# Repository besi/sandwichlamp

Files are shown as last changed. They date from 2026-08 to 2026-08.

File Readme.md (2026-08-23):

# Sandwich Lamp

## Pinout

| Pin | Function |
|-----|---|
| 13  | Enable 12V |
| 18  | Neopixel |
| 14  | Touch 1 |
| 32  | Touch 2 |
| 4 | Touch 3 |
| 34  | Button 1 |
| 33  | Button 2 |
| 39  | Button 3 |
| 36  | Button 4 |
| 35  | Button X |
| 27  | Radar TX |
| 12  | Radar RX |
| 19  | I2C SCL |
| 23  | I2C SDA |
| 16  | Battery Sens |
| 2 | Brightness |
| 5 | Onboard LED  |
| 0 | OneWire |

## Installation

```
import mip
mip.install("github:robert-hh/BME280")
```

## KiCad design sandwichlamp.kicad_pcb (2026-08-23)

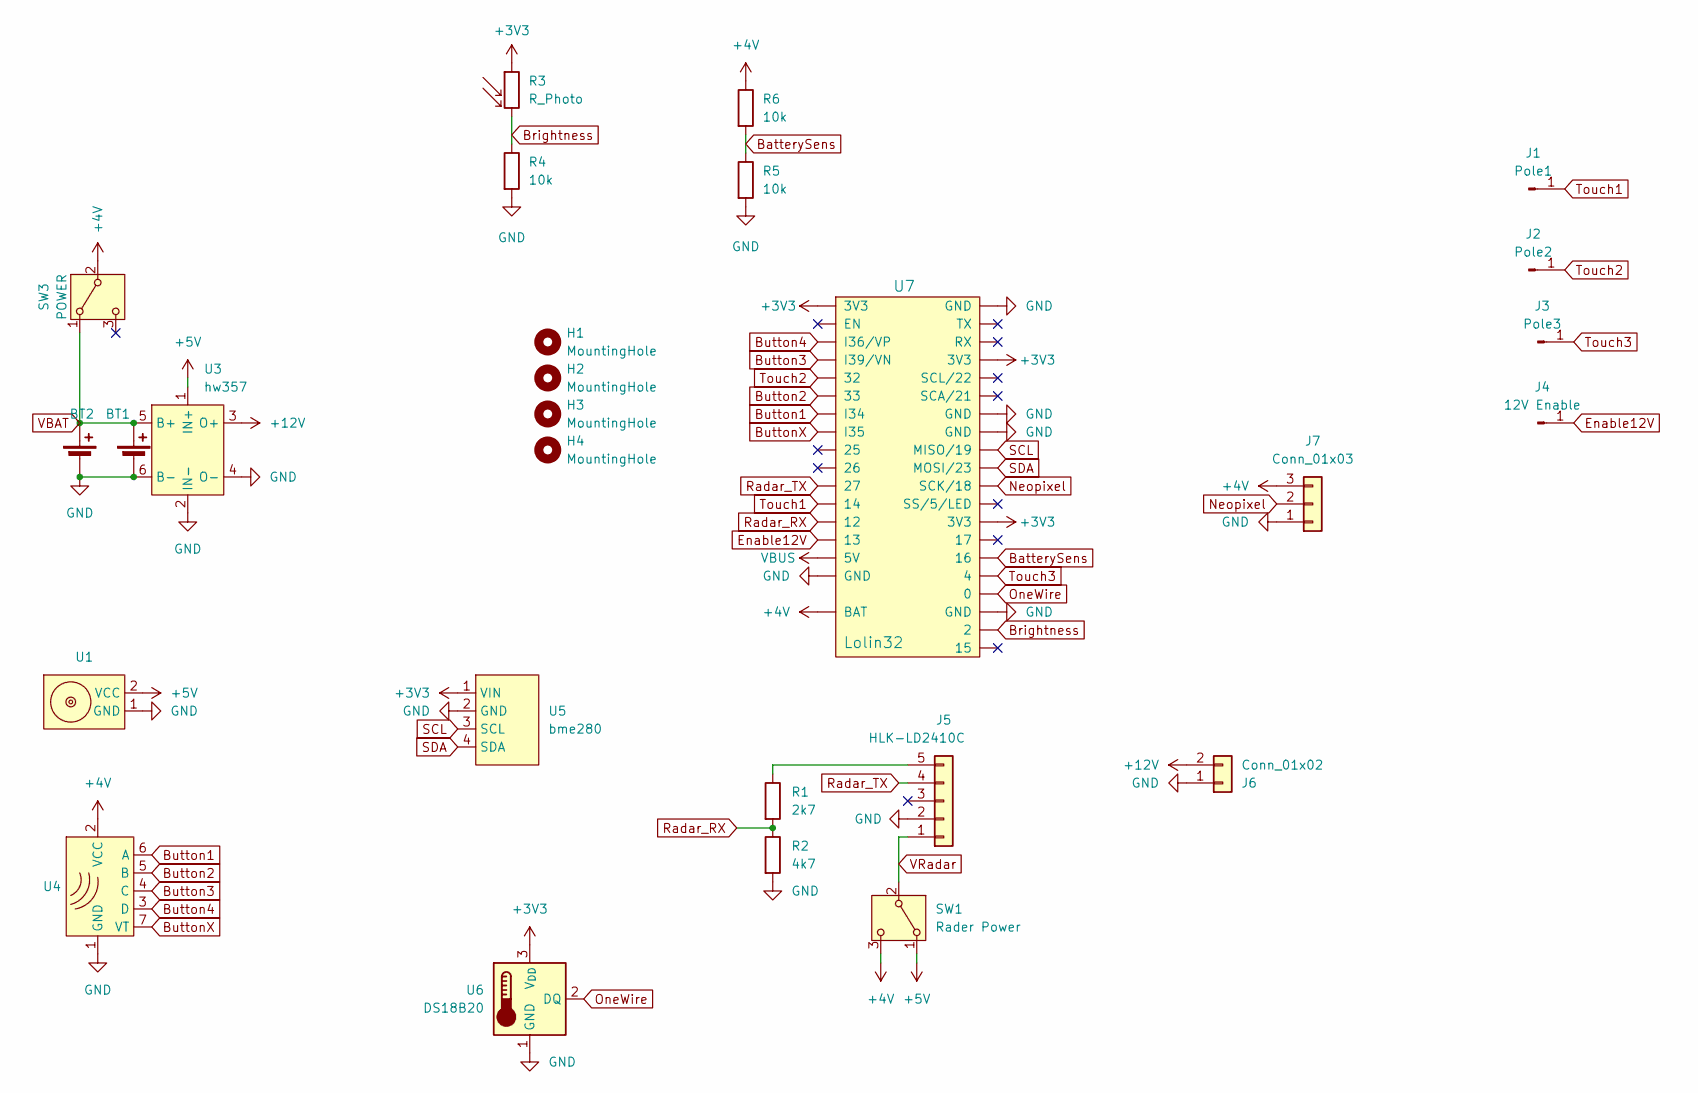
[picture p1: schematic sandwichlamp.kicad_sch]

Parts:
BT1: Battery_Cell; JST_PH_S2B-PH-SM4-TB_1x02-1MP_P2.00mm_Horizontal
BT2: Battery_Cell; JST_PH_B2B-PH-K_1x02_P2.00mm_Vertical
H1, H2, H3, H4: MountingHole; MountingHole_3.2mm_M3
J1: Pole1; MountingHole_4.3mm_M4_ISO7380_Pad_TopOnly
J2: Pole2; MountingHole_4.3mm_M4_ISO7380_Pad_TopOnly
J3: Pole3; MountingHole_4.3mm_M4_ISO7380_Pad_TopOnly
J4: 12V Enable; PinHeader_1x01_P2.54mm_Vertical
J5: HLK-LD2410C; PinHeader_1x05_P2.54mm_Vertical
J6: Conn_01x02; PinHeader_1x02_P2.54mm_Vertical
J7: Conn_01x03; PinHeader_1x03_P2.54mm_Vertical
R1: 2k7; R_Axial_DIN0207_L6.3mm_D2.5mm_P7.62mm_Horizontal
R2: 4k7; R_Axial_DIN0207_L6.3mm_D2.5mm_P7.62mm_Horizontal
R3: R_Photo; R_LDR_5.0x4.1mm_P3mm_Vertical
R4, R5, R6: 10k; R_0805_2012Metric_Pad1.20x1.40mm_HandSolder
SW1: Rader Power; PinHeader_1x03_P2.54mm_Vertical
SW3: POWER; as12ap
U1: magnetic-charger
U3: hw357
U4: RX480E; radio-receiver
U5: bme280
U6: DS18B20; TO-92L_Inline_Wide
U7: Lolin32; lolin32

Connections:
+3V3: R3.1, U5.1 (VIN), U6.3 (V_{DD}), U7.1 (3V3), U7.20 (3V3), U7.29 (3V3)
+4V: J7.3, R6.1, SW1.3 (C), SW3.2 (B), U4.2 (VCC), U7.37 (BAT)
+5V: SW1.1 (A), U1.2 (VCC), U3.1 (IN+)
+12V: J6.2, U3.3 (O+)
BatterySens: R5.1, R6.2, U7.31 (16)
Brightness: R3.2, R4.1, U7.35 (2)
Button1: U4.6 (A), U7.7 (I34)
Button2: U4.5 (B), U7.6 (33)
Button3: U4.4 (C), U7.4 (I39/VN)
Button4: U4.3 (D), U7.3 (I36/VP)
ButtonX: U4.7 (VT), U7.8 (I35)
Enable12V: J4.1, U7.14 (13)
GND: BT1.1 (-), BT2.2 (-), J5.2, J6.1, J7.1, R2.2, R4.2, R5.2, U1.1 (GND), U3.2 (IN-), U3.4 (O-), U3.6 (B-), U4.1 (GND), U5.2 (GND), U6.1 (GND), U7.16 (GND), U7.17 (GND), U7.23 (GND), U7.24 (GND), U7.34 (GND)
Neopixel: J7.2, U7.27 (SCK/18)
unnamed: J5.5, R1.1
OneWire: U6.2 (DQ), U7.33 (0)
Radar_RX: R1.2, R2.1, U7.13 (12)
Radar_TX: J5.4, U7.11 (27)
SCL: U5.3 (SCL), U7.25 (MISO/19)
SDA: U5.4 (SDA), U7.26 (MOSI/23)
Touch1: J1.1, U7.12 (14)
Touch2: J2.1, U7.5 (32)
Touch3: J3.1, U7.32 (4)
VBAT: BT1.2 (+), BT2.1 (+), SW3.1 (A), U3.5 (B+)
VBUS: U7.15 (5V)
VRadar: J5.1, SW1.2 (B)

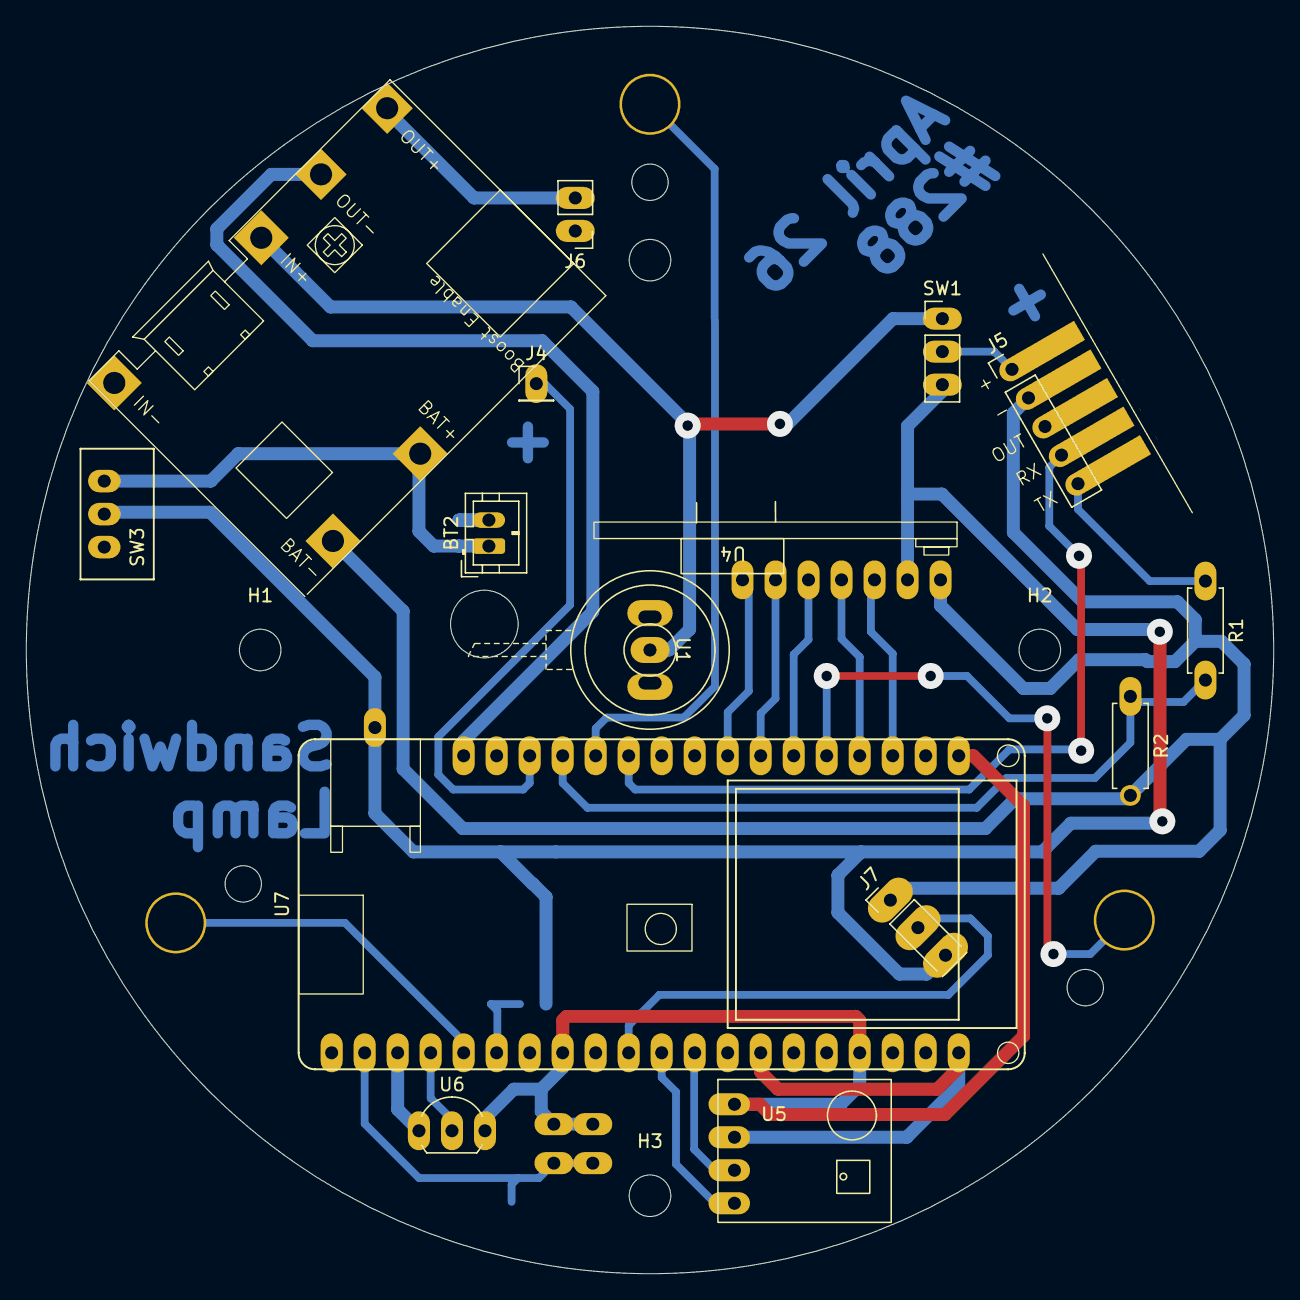
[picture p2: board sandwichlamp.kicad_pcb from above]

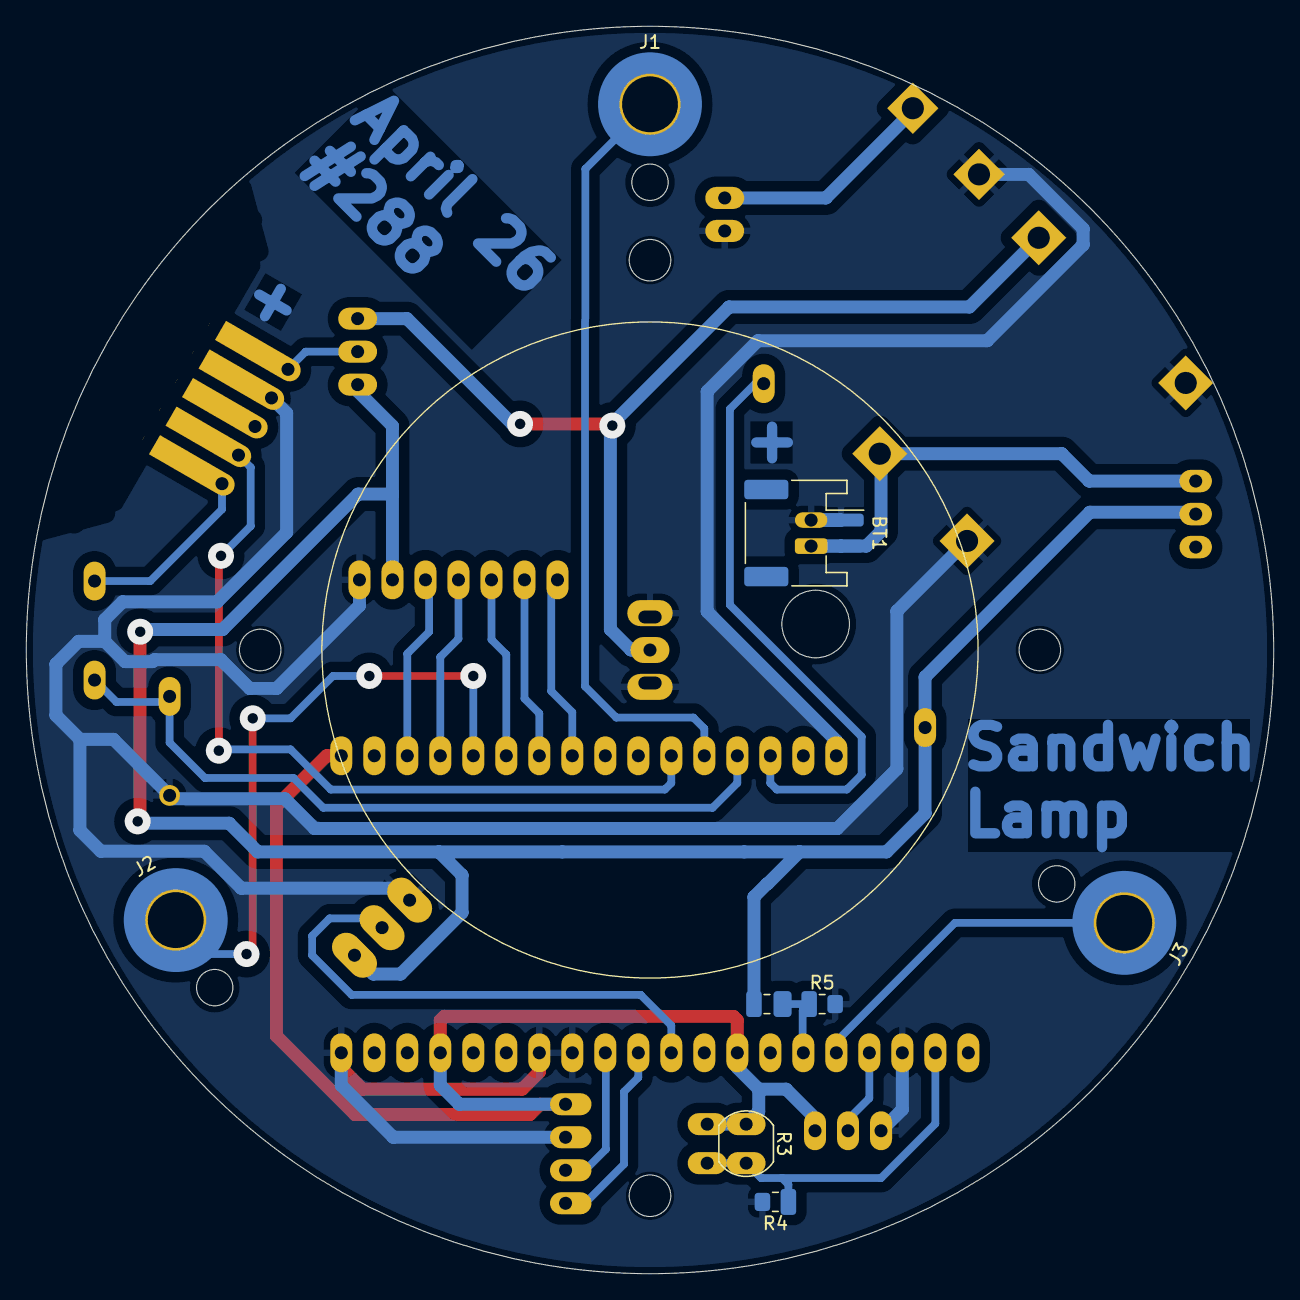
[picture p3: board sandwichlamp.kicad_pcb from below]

Board: 2 copper layers, 96.0 x 96.0 mm, 27 parts (8 on the bottom side), 25 nets.

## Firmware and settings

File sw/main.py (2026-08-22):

from machine import Pin, PWM
import asyncio
from primitives import ESP32Touch, Pushbutton
from  neopixel import NeoPixel
pixelCount = 44
np = NeoPixel(Pin(18), pixelCount)

touch1_pin = 14
touch2_pin = 32
touch3_pin = 4

button_a_pin = 34
button_b_pin = 33
button_c_pin = 39
button_d_pin = 36

enable12v_pin = 13

pwm_start = 610
pwm_end = 1020
pwm_steps = (pwm_end-pwm_start)/20
pwm = PWM(Pin(enable12v_pin), freq=1000)          # create a PWM object on a pin


mode_max = 2
mode = 1
intensity = 10 # 0 .. 20

def down():
    global intensity
    intensity = max(0, intensity -1 )
    print(f"Down {intensity}")

    update_mode(False)

def up():
    global intensity
    intensity = min(20, intensity + 1)
    print(f"Up {intensity}")

    update_mode(False)

def update_mode(modeChanged = True):
    global mode
    global intensity
    
    print(f"Mode = {mode}")
    if mode != 1 and modeChanged:
        pwm.duty(0)
    if mode == 1:
        if modeChanged and pwm.duty() > 1:
            pwm.duty(0)
        else:
            pwm.duty(int(intensity * pwm_steps)+pwm_start)
        

def change_mode():
    global mode
    if mode == mode_max:
        mode = 1
    else:
        mode += 1
    update_mode()
            
def button(number):
    print(f"Pressed Button #{number}")
    if number == 1:
        np.fill((25,0,0))
    elif number == 2:
        np.fill((0,25,0))
    elif number == 3:
        np.fill((0,0,25))
    elif number == 4:
        np.fill((0,0,0))
    np.write()
    
async def main():
    ESP32Touch.threshold(95)
    t1 = ESP32Touch(Pin(touch1_pin), suppress=True)
    t1.release_func(lambda : down())
    t2 = ESP32Touch(Pin(touch2_pin), suppress=True)
    t2.release_func(lambda : change_mode())
    t3 = ESP32Touch(Pin(touch3_pin), suppress=True)
    t3.release_func(lambda : up())

    pb1 = Pushbutton(Pin(button_a_pin, Pin.IN, Pin.PULL_UP))
    pb1.press_func(button, (1,))
    pb2 = Pushbutton(Pin(button_b_pin, Pin.IN, Pin.PULL_UP))
    pb2.press_func(button, (2,))
    pb3 = Pushbutton(Pin(button_c_pin, Pin.IN, Pin.PULL_UP))
    pb3.press_func(button, (3,))
    pb4 = Pushbutton(Pin(button_d_pin, Pin.IN, Pin.PULL_UP))
    pb4.press_func(button, (4,))

    update_mode()
    while True:
        await asyncio.sleep(1)

asyncio.run(main())

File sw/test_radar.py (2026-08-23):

from machine import Pin, UART
import utime
import ld2410

boardled = Pin(5, Pin.OUT)
boardled.off()

print('-----------CONFIGURATION----------------')
uart1 = UART(1, baudrate = 256000, tx=Pin(27), rx=Pin(12), timeout = 3)
human_sensor = ld2410.LD2410(uart1)
human_sensor.enable_config()
#human_sensor.Maximum_distance_gate_and_unoccupied_duration_parameters_configuration(2,2,50) # 2-->8,2-->8,0-->65535 
#human_sensor.read_parameter()
#human_sensor.distance_gate_sensitivity_configuration(1,4,4)
human_sensor.read_firmware_version()
#human_sensor.set_serial_port_baud_rate(0x0007) #0007 --> 256000 ,  0x0005-->115200
#human_sensor.restore_factory_settings()
#human_sensor.reboot_module() #--> end_config failure
#human_sensor.bluetooth_setting(0x0001)  #0x0001-->ON 0x0000-->OFF 
human_sensor.get_mac_address()
#human_sensor.set_bluetooth_password()

# Distance_resolution_setting 0.2m  with value 1
# Distance_resolution_setting 0.75m with value 0
#human_sensor.query_distance_resolution_setting()
human_sensor.distance_resolution_setting(1)

human_sensor.end_config()
#human_sensor.enable_engineering_mode()
#human_sensor.end_engineering_mode()

utime.sleep(5)

print('-----------DECTECTION----------------')
while True: 
    human_sensor.send_command_report_data()
    #human_sensor.print_meas()
    human_sensor.human_detection(boardled,50,50)
    utime.sleep(.1)

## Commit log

2026-04-01 Update PCB
    [sandwichlamp.kicad_pcb, sandwichlamp.kicad_sch]
2026-04-01 Add radar sensor
    [sandwichlamp.kicad_pcb, sandwichlamp.kicad_sch]
2026-04-02 Add BME280 sensor
2026-04-02 Update magnetic charger lib which shows the outline of the cable
2026-04-02 Align the radar with the cable
    [sandwichlamp.kicad_pcb]
2026-04-02 Add BME280 and radio-receiver and continue with the placement of the components
    [sandwichlamp.kicad_pcb, sandwichlamp.kicad_sch]
2026-04-02 Add new esp footprint
    [sandwichlamp.kicad_pcb, sandwichlamp.kicad_sch]
2026-04-02 Add the new Lolin32 footprint
    [sandwichlamp.kicad_pcb, sandwichlamp.kicad_sch]
2026-04-02 Update Lolin Footprint
    [sandwichlamp.kicad_pcb]
2026-04-03 Add power switch and power switch for the radar
    [sandwichlamp.kicad_pcb, sandwichlamp.kicad_sch]
2026-04-03 Add battery pad to the Lolin where the battery voltage can be taken for the ESP
    [sandwichlamp.kicad_pcb, sandwichlamp.kicad_sch]
2026-04-03 Add M3 mounting holes
    [sandwichlamp.kicad_pcb, sandwichlamp.kicad_sch]
2026-04-03 Add a light sensor and the labels for the existing components
    [sandwichlamp.kicad_pcb, sandwichlamp.kicad_sch]
2026-04-03 Add battery sensing
    [sandwichlamp.kicad_sch]
2026-04-03 Add Neopixel footprint and do the preliminary routing
    [sandwichlamp.kicad_pcb, sandwichlamp.kicad_sch]
2026-04-03 Relocate the light sensor so that it can actually sense some light from the top of the lamp
    [sandwichlamp.kicad_pcb, sandwichlamp.kicad_sch]
2026-04-05 Make sure input-only pins are used as such
    [sandwichlamp.kicad_sch]
2026-04-05 Fix the touch buttons
    [sandwichlamp.kicad_pcb, sandwichlamp.kicad_sch]
2026-04-05 Cleanup schematic and pcb
    [sandwichlamp.kicad_pcb, sandwichlamp.kicad_sch]
2026-04-05 Disconnect the two 5V nets from one another
    [sandwichlamp.kicad_pcb, sandwichlamp.kicad_sch]
2026-04-05 Relocate the logo
    [sandwichlamp.kicad_pcb]
2026-04-06 Thicker GND trace for the temperature sensor
    [sandwichlamp.kicad_pcb]
2026-04-07 Run DRC
    [sandwichlamp.kicad_pcb, sandwichlamp.kicad_sch]
2026-04-10 Prepare for plotting
    [sandwichlamp.kicad_pcb]
2026-04-10 Remove the obsolete c3-pico as well as the wemos d1 mini git sub module
2026-04-11 Reverse the polarity of the SMD Battery Connector
    [sandwichlamp.kicad_pcb, sandwichlamp.kicad_sch]
2026-04-11 Add test code for the bme280 sensor
2026-04-11 Hide the pin numbers of the ESP32 in schematic since it is very confusing with the GPIO numbers being shown at the same time
    [sandwichlamp.kicad_sch]
2026-04-11 Update the PWM test so that it runs in a loop
2026-04-11 Switch the radar TX RX pins
2026-04-21 Test the 12V lamp with both on/off and PWM
2026-04-22 Increase the timeout for the LD2410 sensor
2026-04-22 Don't set a maximum gate (0-8) which would limit the responsive ness of the sensor
2026-04-30 Fix the main.py code so that the lamp can be toggled
    [main.py]
2026-08-23 Use the onboard LED
2026-08-23 Update component libraries
    [sandwichlamp.kicad_pcb]
